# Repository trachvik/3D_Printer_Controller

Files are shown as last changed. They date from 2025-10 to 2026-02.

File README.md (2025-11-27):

# 3D Printer Controller

## Introduction

*This repository presents an early prototype of the controller. A custom PCB is planned as the next development step, replacing the breadboard setup.*[^1]

This project aims to create a macropad-like device with a gimbal BLDC motor–based haptic knob as its primary control element. In addition to the haptic knob and the 4×4 keyboard matrix, the controller also includes an OLED display and two mechanical encoders.

Most 3D printers ship with a simple LCD and a single mechanical encoder, which makes navigation slow and unintuitive. This controller aims to provide a more user-friendly, faster, and highly customizable way to control a 3D printer.

Users can define custom G-codes and macros and trigger them using hotkeys.
The haptic knob is intended for tasks such as:

- axis jogging  
- temperature adjustments  
- tool selection  
- Z-offset tuning  
- feedrate / flow changes  
- and more  

The step size for parameter changes can be adjusted using one of the mechanical encoders. The second encoder is used for navigating through menus displayed on the OLED screen.

Depending on the firmware, the controller can serve multiple purposes — not only for 3D printers, but also as a general control surface for other devices or Home Assistant.

---

## Implementation

### Haptic Element

The haptic control element is based on an outer-rotor gimbal BLDC motor, chosen for its high torque and suitability for direct-drive applications.  
The motor is driven by a [TMC6300](datasheets/TMC6300.pdf), a compact, low-voltage, and highly efficient 3-phase driver.  
Rotor position is measured using the [AS5048A](datasheets/as5048.pdf), a 14-bit magnetic angle sensor that provides precise feedback for torque and position control.

The haptic behavior is implemented using the [SimpleFOC](https://simplefoc.com) library, which handles the Field-Oriented Control (FOC) algorithms.

The BLDC motor is used to generate programmable haptic effects such as:

- detents  
- dynamic torque feedback  
- virtual resistance / friction  
- end-stops corresponding to printer limits or menu boundaries  

### Other Components

I chose to use an ESP32 module because it has integrated Wi-Fi, which simplifies the design.  
For the future PCB version, I will have to use an ESP32 module with a homologation/CE-certified RF design.

The implementation of the remaining components is straightforward.  
An I/O expander is required because the TMC6300 and the keyboard matrix alone comsume 14 I/O pins.  
A simplified block diagram is shown below:

block_diagram

---

## Current Features

- Users are prompted to enter Wi-Fi credentials, printer host, port, and custom hotkeys via a configuration access point at first startup  
  (for the password, users can scan an included QR code).  
- Users can reopen the configuration menu by pressing the left encoder for 3 seconds.  
- Keyboard hotkeys are functional.  
- Step size can be adjusted using the left encoder.  
- The right encoder is used for display/menu navigation.  
- The haptic knob can be used to increase or decrease the X-axis position.

### Prototype Photo

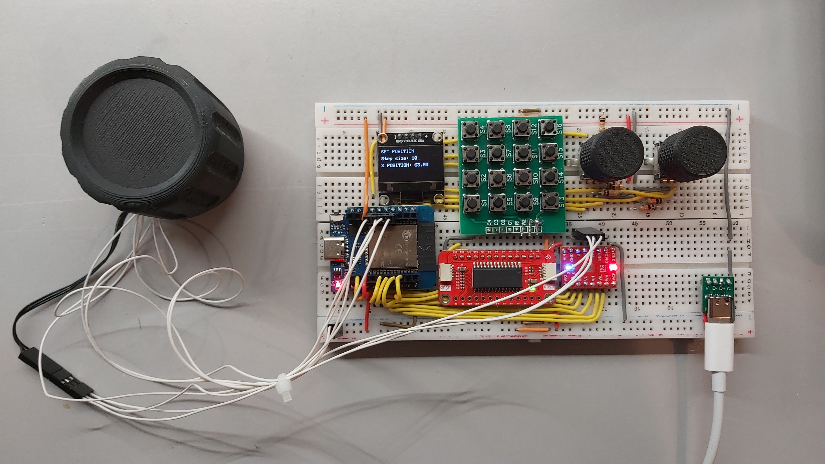
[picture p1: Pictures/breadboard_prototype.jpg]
breadboard_prototype


### Demo
 
[Video](https://drive.google.com/file/d/1ionz915SD3VQXqB1Lr0lfkvmCnSRa0wJ/view?usp=sharing)

[^1]: This version of the project serves as a proof of concept. Features are intentionally limited and primarily intended to validate the hardware functionality.

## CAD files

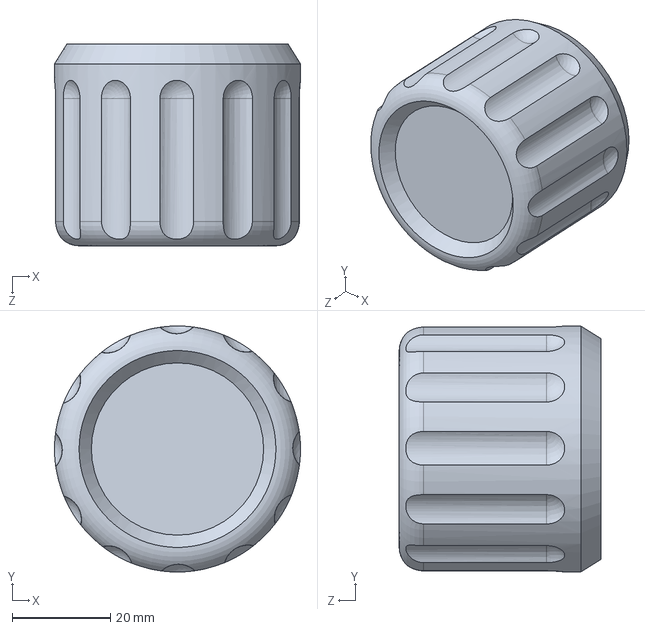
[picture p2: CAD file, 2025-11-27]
SOLIDWORKS/knob_cover.SLDPRT
50.0 x 50.0 x 41.0 mm

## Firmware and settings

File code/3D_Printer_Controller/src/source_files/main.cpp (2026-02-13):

#include <Arduino.h>

#include "header_files/wifiConnect.h"
#include "header_files/hapticControl.h"
#include "header_files/printerControl.h"
#include "header_files/Display.h"
//#include <Wire.h>

#define setup_clear_PIN 14
#define encoderHC_PIN0 35
#define encoderHC_PIN1 39
#define encoderPC_PIN0 33
#define encoderPC_PIN1 34


hapticControl HC(MagneticSensorSPI(AS5048_SPI, 5), BLDCMotor(7), BLDCDriver6PWM(15, 16, 17, 4, 12, 32), 5, encoderHC_PIN0, encoderHC_PIN1);

// Pins on the MCP23017 I/O expander
byte rowPins[4] = {11, 10, 9, 8}; //connect to the row pinouts of the keypad
byte colPins[4] = {12, 13, 14, 15}; //connect to the column pinouts of the keypad

Display display;

printerControl PC(rowPins, colPins, encoderPC_PIN0, encoderPC_PIN1, &display);
bool printerControlinit = true;

wifiConnect wifiCon(&display);

void setup()
{
  //pinMode(setup_clear_PIN, INPUT_PULLUP);
  //Serial.begin(115200);

  /*if (display.begin(SSD1306_SWITCHCAPVCC, 0x3C))
  {
    //Serial.println("Display initialized");
    display.clearDisplay();
    display.display();
  } else
  {
    Serial.println("Warning: display.begin() failed");
  }*/

  //wifiCon.init();
  // This prevents PC.init() from beeing called before saving values to prefs
 
  /*if(wifiCon.config_saved)
  {
    PC.init();
    printerControlinit = false;
  }*/
  // initialize HC
  HC.init();

  xTaskCreatePinnedToCore
  (
    hapticControl::startTask, // Call the static function
    "MotorTask",
    2048,         // Change stack size if necessary
    &HC, // Pass the instance as parameter
    1, // reduce priority so it doesn't starve main loop
    NULL,
    1 // pin to core 1
  );
}

//long clear_timeout = 0;

void loop()
{
  /*if(digitalRead(setup_clear_PIN) == LOW && millis() - clear_timeout > 3000) // this clears prefs after 3s hold
  {
    wifiCon.config_clear();
    display.setCursor(0,0);
    display.printText("Config cleared!\n", 1, 1);
    delay(1000);
    wifiCon.init();
  }
  else if(digitalRead(setup_clear_PIN) == HIGH)
  {
    clear_timeout = millis();
  }
  /////////////////// Handle haptic control related opearation in printerControl | TO DO HC as object in printerControl?
  if (HC.step_count != HC.step_count_old)
  {
    int sign = (HC.step_count > HC.step_count_old) ? 1 : -1;
    //display.setCursor(0,0);
    //display.printText("step_count: " + String(HC.step_count) + "\n", 1, 1);
    // Serial.println(HC.step_count);
    PC.knobPendingChange(sign);
    HC.step_count_old = HC.step_count;
  }
  if(HC.encoder_val != HC.encoder_val_old)
  {
    PC.setStepSize(HC.encoder_val);
    HC.encoder_val_old = HC.encoder_val;
  }
////////////////////////////////////////////////////////////////////////////////////////////////////////////////////////

  if(wifiCon.config_saved)
  {
    if(printerControlinit) PC.init();
    else PC.loop();
    printerControlinit = false;
    //Serial.println("FLAG");
  }
  wifiCon.server.handleClient();
  //HC.loop();
  //PC.loop();

  display.printf("step_count: %d\n", HC.step_count);  */
}

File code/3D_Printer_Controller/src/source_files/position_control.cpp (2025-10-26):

#include "header_files/hapticControl.h"

hapticControl HC = hapticControl(MagneticSensorSPI(AS5048_SPI, 5), BLDCMotor(7), BLDCDriver6PWM(15, 16, 17, 4, 21, 22), 5);
RotaryEncoder encoder(35, 39, RotaryEncoder::LatchMode::TWO03);
long time_past = 0;

void setup()
{
  Serial.begin(115200);
  // initialize HC and pass the rotary encoder to it
  HC.encoderInit(encoder);
  HC.init();
}

void loop()
{
  HC.loop();

  if(millis() - time_past > 1000)
  { 
    Serial.println("Step Count: ");
    Serial.println(HC.step_count);
    time_past = millis();
  }
}

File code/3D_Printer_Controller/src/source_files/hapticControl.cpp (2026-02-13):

#include "header_files/hapticControl.h"
 
hapticControl::hapticControl(MagneticSensorSPI sensor_init, BLDCMotor motor_init, BLDCDriver6PWM driver_init, int voltage_limit, int encoder_PIN0, int encoder_PIN1)
  : sensor(sensor_init), motor(motor_init), driver(driver_init), voltage_limit(voltage_limit),
    encoder(encoder_PIN0, encoder_PIN1, RotaryEncoder::LatchMode::TWO03)
{
  step_size = _2PI/(float)(num_steps > 0 ? num_steps : 1);  // Avoid division by zero
  num_steps_old = num_steps;
  step_count_old = step_count;
  last_voltage = 0.0;
  voltage_filter_alpha = 0.8;  // Filter strength: lower=smoother, higher=responsive (0.2-0.5)
}

void hapticControl::init()
{
  setNumSteps();
    // initialize magnetic sensor hardware
  sensor.init();
  // diagnostic: check sensor read immediately after init
  // link the motor to the sensor
  motor.linkSensor(&sensor);
  // driver config
  // power supply voltage [V]
  driver.voltage_power_supply = voltage_limit;
  // limit the maximal dc voltage the driver can set
  // as a protection measure for the low-resistance motors
  // this value is fixed on startup
  driver.voltage_limit = voltage_limit;
  // pwm frequency to be used [Hz]
  // for atmega328 fixed to 32kHz
  // esp32/stm32/teensy configurable
  // Lower frequency reduces audible noise but may affect smoothness
  // Try: 20000-25000 Hz for balance between performance and noise
  driver.pwm_frequency = 40000;  // Reduced from 32000 to minimize audible noise
  // driver config
  driver.init();
  motor.linkDriver(&driver);
  // set motion control loop to be used
  // set the torque control type
  // Set motor parameters for proper FOC
  //motor.phase_resistance = 12.5; // 12.5 Ohms
  motor.torque_controller = TorqueControlType::voltage;
  // Set motion control loop
  motor.controller = MotionControlType::torque;
  // Set reasonable voltage limit for stable control
  motor.voltage_limit = voltage_limit;
  // use monitoring with serial 
  //Serial.begin(115200);
  // comment out if not needed
  //motor.useMonitoring(Serial);
  // initialize motor
  motor.init();
  // align encoder and start FOC
  motor.initFOC();
  //Serial.println("Motor ready.");
  //start_angle = sensor.getAngle();
  
  // Settle motor at zero torque after calibration
  for (int i = 0; i < 100; i++) {
    motor.loopFOC();
    motor.move(0);
    delayMicroseconds(1000);
  }
  
  _delay(500);

  start_angle = sensor.getAngle();
  last_voltage = 0.0f;  // Ensure filter starts at zero
}
void hapticControl::startTask(void* _this)
{
    // Convert the passed pointer back to hapticControl instance
    hapticControl* controller = (hapticControl*)_this;
    
    static uint32_t lastCheck = 0;
    /*if (millis() - lastCheck > 2000)
    {
        lastCheck = millis();
        
        UBaseType_t space_left = uxTaskGetStackHighWaterMark(NULL);
        Serial.printf("Least amount of stack space that has remained for the task since the task was created: %d bytes\n", space_left);
        
        if (space_left < 200)
        {
            Serial.println("Warning: very low stack space in xTaskCreatePinnedToCore");
        }
    }*/
    
    // Now call the actual loop method
    controller->loop();
}

void hapticControl::loop()
{
  while(1)
  {
    sensor.update();
    motor.loopFOC();
    motor.move(3);
    delay(5);
  }
}

long last_millis = 0;

void hapticControl::setNumSteps() // TO DO interrupt?
{
  // Update encoder state
  encoder.tick();
  int curPos = encoder.getPosition() / 2;
  /*if(millis() - last_millis > 500)
  {
    Serial.print("Encoder position HC : ");
    Serial.println(curPos);
    last_millis = millis();
  }*/

  // compute coarse relative position in blocks of 16 (adjust as needed)
  encoder_val = abs(curPos - (curPos - curPos % 6)) + 1;  // 6 ... number of step increments | numbers [1,6]
  // store into the object's num_steps member
  // encoder_val 1 = smooth mode (0 steps), 2-6 = 4, 8, 12, 16, 20 steps
  if (encoder_val == 1) {
    num_steps = 0;  // Smooth mode
  } else {
    num_steps = (7 - encoder_val) * 4;  // 4, 8, 12, 16, 20 steps
  }
}

/*void hapticControl::encoderInit(RotaryEncoder &encoder)
{
  // Store the address of the passed encoder
  this->encoder = &encoder;
}*/

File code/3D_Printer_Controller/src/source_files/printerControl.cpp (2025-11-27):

#include "header_files/printerControl.h"

printerControl* printerControl::instance = nullptr; // Inicialization of the static instance pointer

static char keys[4][4] = {
    {'0','1','2','3'},
    {'4','5','6','7'},
    {'8','9','A','B'},
    {'C','D','E','F'}
};

printerControl::printerControl(byte rowPins[4], byte colPins[4], int encoder_PIN0, int encoder_PIN1, Display *disp)
  : kpd(makeKeymap(keys), rowPins, colPins, 4, 4, &extender), display(disp), encoder_PIN0(encoder_PIN0), encoder_PIN1(encoder_PIN1),
    encoder(encoder_PIN0, encoder_PIN1, RotaryEncoder::LatchMode::TWO03)
{
  current_mode = PC_IDLE;
  PATH = "/websocket";
  connected = false;
}

void IRAM_ATTR printerControl::readEncoderISR()
{
  encoder.tick(); 
}

void printerControl::Wrapper()
{
    if (instance != nullptr) {
        instance->readEncoderISR(); // Call the actual ISR method
    }
}

bool printerControl::init()
{
    extender.init();
    Preferences prefs;
    prefs.begin("config", true);
    String HOST = prefs.getString("HOST");
    int PORT = prefs.getInt("PORT");
    //save gcodes to local array:
    for(int i = 0; i < 16; i++)
    {
      //Serial.print("Key: ");Serial.println(prefs.getString(((String)i).c_str()));
      this->gcode[i] = prefs.getString(((String)i).c_str());
      //Serial.printf("gcode[%i]: %s\n", i, gcode[i]);
    }
    prefs.end();

    //webSocketInit:
    url = "http://" + HOST;
    String header = "Origin: " + url;
    webSocket.setExtraHeaders(header.c_str());
    webSocket.begin(HOST, PORT, PATH);

    /**this call passes the address of webSocketEvent into the WebsocketClient object
     * library stores this address in a function-pointer variable
     * when an event occurs, library calls the function through the pointer inside its own routine webSocket.loop()
     */
    //viz
    https://gitlab.fel.cvut.cz/trachvik/bachelor-project/-/blob/main/code/3D_Printer_Controller/lib/arduinoWebSockets-master/src/WebSocketsClient.cpp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

    // Using a lambda because member functions cannot be used as function pointers directly
    webSocket.onEvent([this](WStype_t type, uint8_t * payload, size_t length) {
        this->webSocketEvent(type, payload, length);
    });
    webSocket.setReconnectInterval(15000);

    instance = this; // Set the static instance pointer to this instance
    // Attach interrupts for the encoder pins
    attachInterrupt(digitalPinToInterrupt(encoder_PIN0), Wrapper, CHANGE);
    attachInterrupt(digitalPinToInterrupt(encoder_PIN1), Wrapper, CHANGE);

    return true;

    //TO DO return 0 if it fails
}

//websocket handler function
void printerControl::webSocketEvent(WStype_t type, uint8_t * payload, size_t length)
{
  switch(type)
  {
    case WStype_DISCONNECTED:
      Serial.println("[WSc] Disconnected!");
      //display->setCursor(0,0);
      //display->printText("Cannot connect to printer!", 1, true);
      connected = false;
      break;
    case WStype_CONNECTED:
      Serial.println("[WSc] Connected!");
      //display->setCursor(0,0);
      //display->printText("Connected to printer!", 1, true);
      // send subscribe once on connect
      //printer_subscribe();
      connected = true;
      connect_display_flag = true;
      //Defer Display([this](){this->displayShow(); });
      // Set state to indicate we need to send Query
        connection_state = 1;
        last_command_millis = millis();
      break;
    case WStype_TEXT:
      if(connected)
      {
        data = (char*)payload;
        //Defer Display([this](){this->displayShow(); });
        //Defer Parse([this](){this->parse_data(); });
        newDataAvailable = true;
      }
      break;
  }
}

void printerControl::parse_data()
{
  //if(parse_flag)
  //{
    DynamicJsonDocument doc(4096); // adjust size if needed
    DeserializationError error = deserializeJson(doc, data.c_str());
    if (error)
    {
      Serial.print(F("deserializeJson() failed: "));
      Serial.println(error.f_str());
      Serial.printf("payload: %s\n", data);
      return;
    }
    // Extract relevant data to root object
    JsonObject root;

    if (doc.containsKey("method")) //subscribe responce
    {
      if(doc["method"] == "notify_status_update")
      {
        root = doc["params"][0].as<JsonObject>();
        //Serial.println("subscribe_flag");
      }
    }
    if (doc.containsKey("result") && doc["result"].is<JsonObject>()) //query responce
    {
      root = doc["result"]["status"].as<JsonObject>();
      //Serial.println("query_flag");
    }

    //parse values from root object
    // extruder
    if (root.containsKey("extruder") && root["extruder"].is<JsonObject>())
    {
      JsonObject ex = root["extruder"].as<JsonObject>();
      if (ex.containsKey("temperature")) ext_temp = ex["temperature"].as<float>();
      if (ex.containsKey("target")) ext_target = ex["target"].as<float>();
    }

    // heater_bed
    if (root.containsKey("heater_bed") && root["heater_bed"].is<JsonObject>())
    {
      JsonObject hb = root["heater_bed"].as<JsonObject>();
      if (hb.containsKey("temperature")) bed_temp = hb["temperature"].as<float>();
      if (hb.containsKey("target")) bed_target = hb["target"].as<float>();
    }

    // position
    if (root.containsKey("toolhead") && root["toolhead"].is<JsonObject>())
    {
      JsonObject hb = root["toolhead"].as<JsonObject>();
      if (hb.containsKey("position"))
      {
        for(int i = 0; i < 4; i++)
          position[i] = hb["position"][i].as<float>();
      }
    }
    // Print values.
      //Serial.printf("Extruder Temperature: %.2f --> %.2f,  Bed Temperature: %.2f --> %.2f \n", ext_temp, ext_target, bed_temp, bed_target);
      //Serial.printf("Position: [%.2f, %.2f, %.2f, %.2f] \n", position[0], position[1], position[2], position[3]);

    //Serial.printf("[WSc] Text: %s\n", payload);
    //display->setCursor(0,10);
    //display->clearDisplay();
    //display->printf("X: %.0f\nY: %.0f\nZ: %.0f\nE: %.0f", position[0], position[1], position[2], position[3]);
    //display->display();

    //parse_flag = false;
    //}
}

String printerControl::dataToSend(bool isQuery)
{
  String data;
  String dataToSend;

  //list of objects to subscribe to:
  //Object -> Object Fields | example: "heater_bed": ["temperature", "target"]
  https://moonraker.readthedocs.io/en/latest/printer_objects/ | list of the objects and their fields
  data += "\"heater_bed\": [\"temperature\", \"target\"],";
  data +=  "\"extruder\": [\"temperature\", \"target\"],";
  data += "\"toolhead\": [\"position\"]"; // target? | position x live_position

  if(isQuery)
  {
    dataToSend = "{\"jsonrpc\": \"2.0\",\"method\": \"printer.objects.query\",\"params\": {\"objects\": {"
      + data + "}}, \"id\": 5434}";
  }
  else
  {
    dataToSend = "{\"jsonrpc\": \"2.0\",\"method\": \"printer.objects.subscribe\",\"params\": {\"objects\": {"
      + data + "}}, \"id\": 5434}";
  }
  return dataToSend;
}
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

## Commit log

2025-09-28 parsingAndSave function
    [AP_connect.dxf]
2025-10-29 printerControl class
2025-11-22 this does not work
    [hapticControl.cpp, main.cpp, printerControl.cpp]
2025-11-22 Revert "SPIFFS"
    This reverts commit 922205d0e255bbdf938d8d1739394a3a180bf734.
    [wifiConnect.cpp]
2025-11-23 clear config button
2025-11-24 Data parsing and second encoder
2025-11-27 README and comments unification
    [knob_cover.SLDPRT]
2026-02-02 Tried some low filtering
2026-02-09 Better filtering, smooth mode, 9V source
2026-02-13 Test-basic torque control move
